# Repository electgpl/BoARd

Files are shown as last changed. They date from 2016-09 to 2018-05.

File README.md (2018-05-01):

# Board

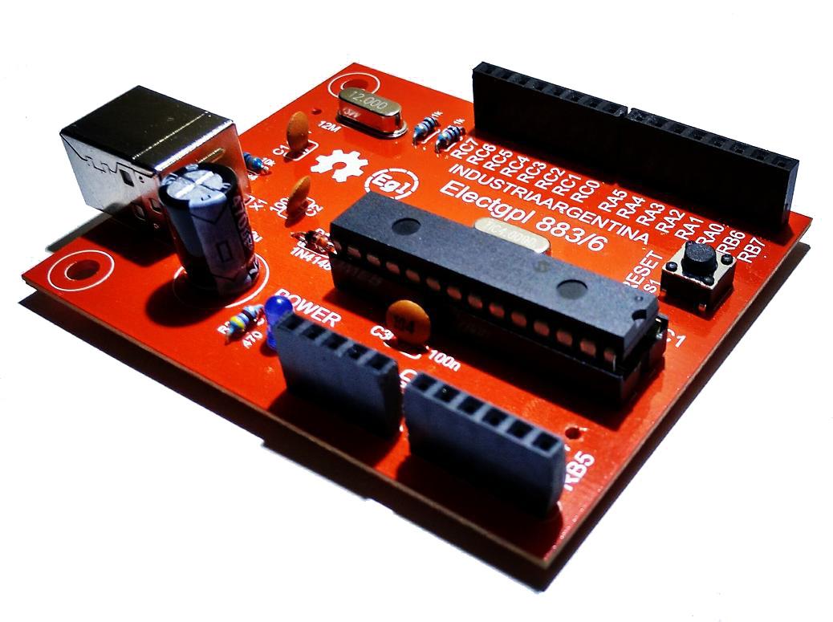
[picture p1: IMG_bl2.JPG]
N|Solid


Placa de desarrollo basada en Microchip de bajo costo, proyecto realizado de manera simple para poder ser replicado por alumnos de escuelas sin la necesidad de importar componentes y con la facilidad de realizar el circuito impreso por ellos mismos en una sola capa

  - [picc] PIC16F883 con Bootloader (Carga de fuente y Terminal Serie)
  - PCB Simple en 1 Layer realizado con Eagle
  - Bootloader oficial Micochip (AN1310) 9600bps
  - Multiples IDEs y lenguajes

Se ha probado con diversos IDEs y Lenguajes con resultados satisfactorios

> [picc] - PCWHD (PICC)
> [mplabx] - MPALB X
> [mikroc] - MikroC
> [ldmicro] - LDmicro
> [eagle] - Eagle

## Lenguajes

* Assembly
* C
* C++
* Basic
* Visual
* Ladder
* Scratch

### Instalacion (Windows)

Se debe descargar el acrhivo zip de la nota AN1310, donde encontraremos el programa ejecutable de Windows.
[AN1310]

License
----

MIT

**Free Software, Hell Yeah!**

   [picc]: <http://www.ccsinfo.com/>
   [mplabx]: <http://www.microchip.com/mplab/mplab-x-ide>
   [eagle]: <https://www.autodesk.com/education/free-software/eagle>
   [mikroc]: <https://www.mikroe.com/mikroc/>
   [ldmicro]: <http://cq.cx/ladder.pl>
   [AN1310]: <http://www.microchip.com/wwwAppNotes/AppNotes.aspx?appnote=en546974>

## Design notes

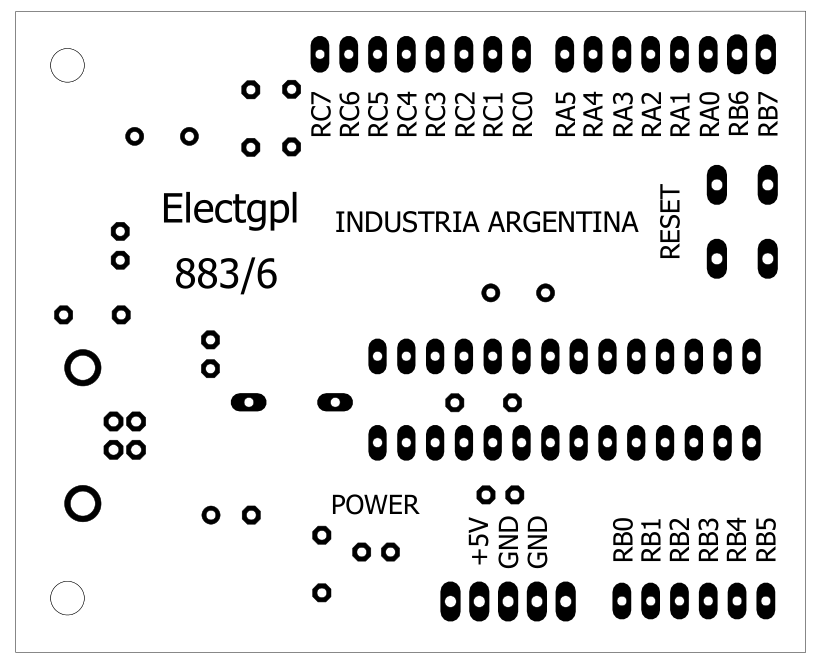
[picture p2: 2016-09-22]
Electgpl F883-6 THT Rev1 SER.PNG

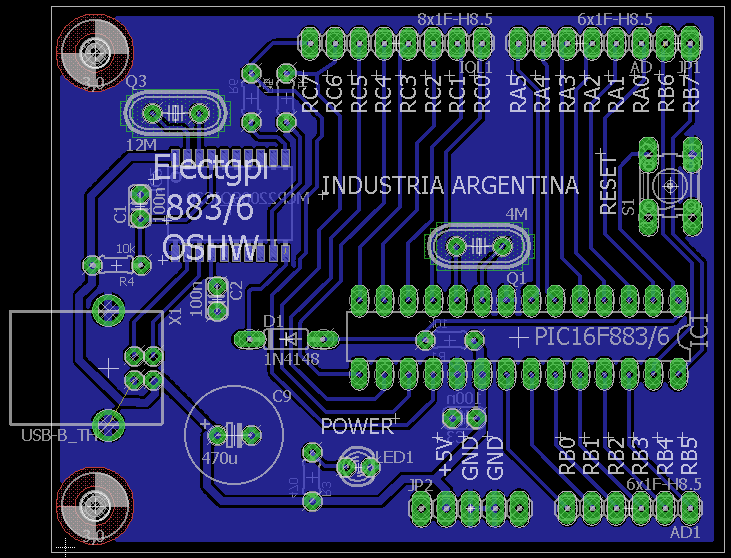
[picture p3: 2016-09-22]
Electgpl F883-6 THT Rev1 DISP.PNG

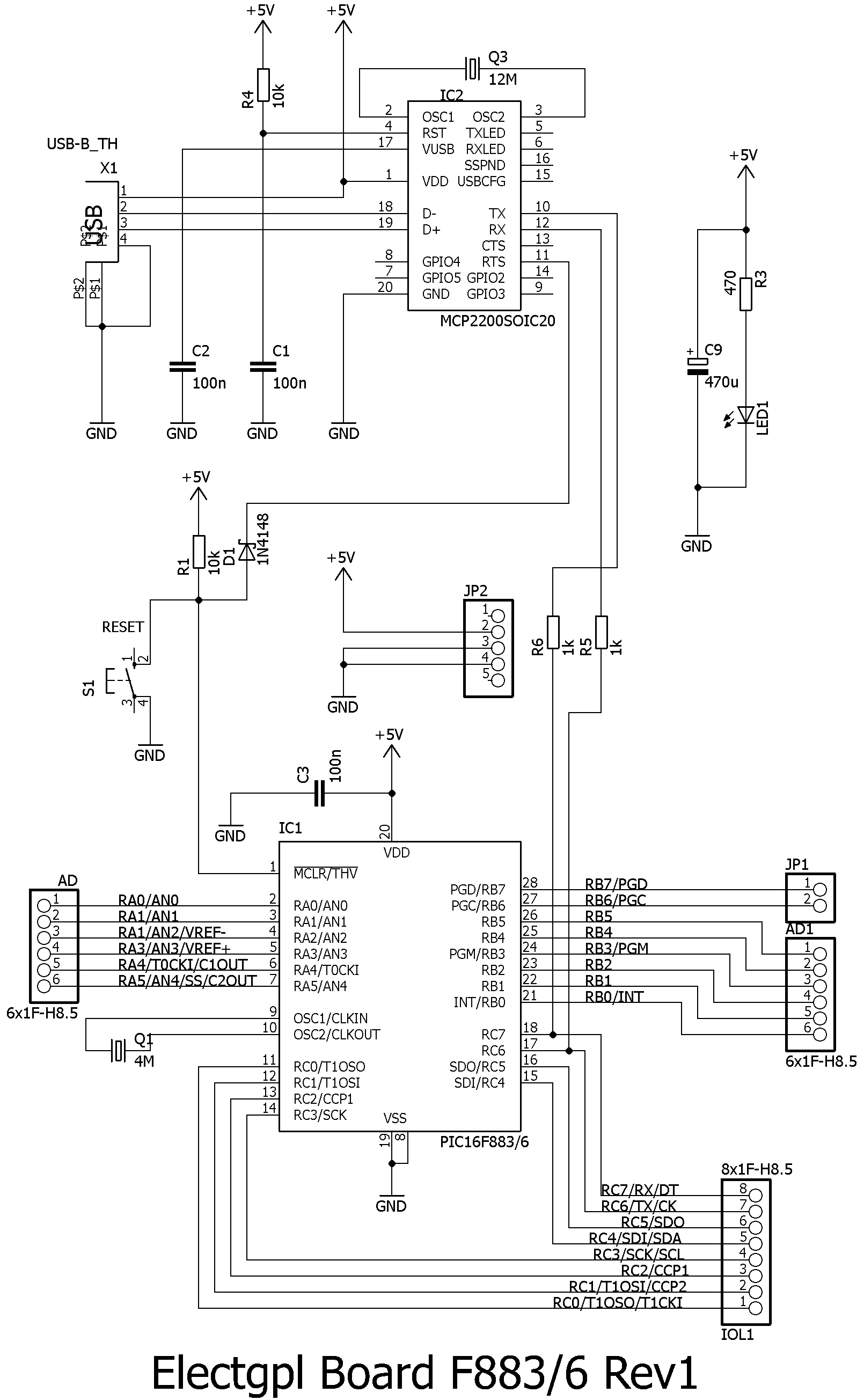
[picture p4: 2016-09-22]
Electgpl F883-6 THT Rev1 SCH.PNG

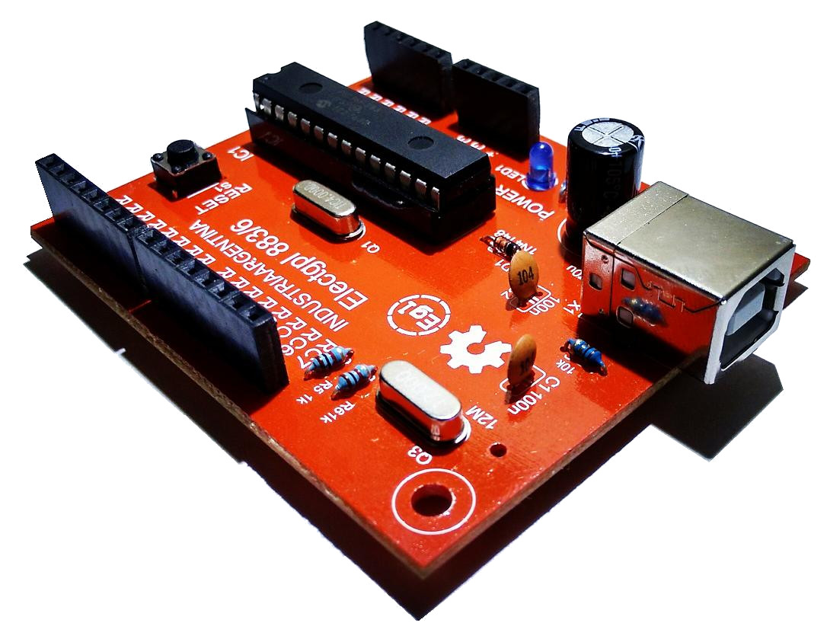
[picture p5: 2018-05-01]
IMG_bl1.JPG

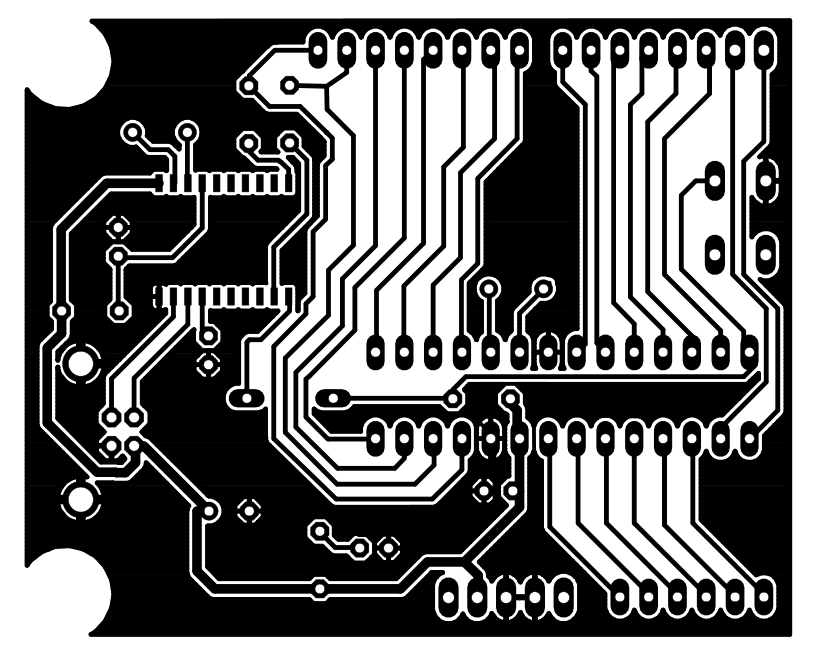
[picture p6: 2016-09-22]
Electgpl F883-6 THT Rev1 PCB.PNG

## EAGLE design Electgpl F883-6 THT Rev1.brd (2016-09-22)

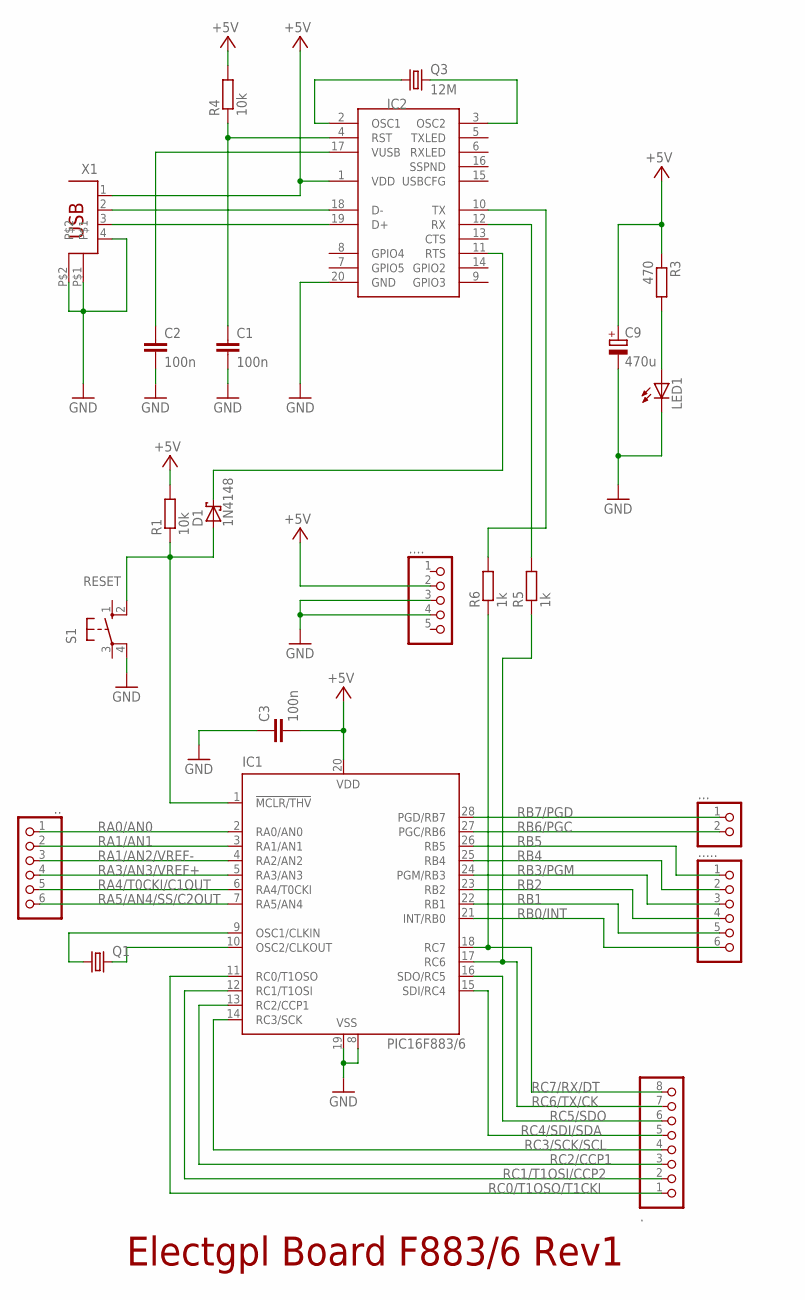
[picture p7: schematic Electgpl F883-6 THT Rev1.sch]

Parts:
.: PINHD-1X8; 1X08
.., .....: PINHD-1X6; 1X06
...: PINHD-1X2; 1X02
....: PINHD-1X5; 1X05
C1, C2, C3: 100n; C025-024X044
C9: 470u; E3,5-10
D1: 1N4148; DO35-7
IC1: PIC16F883/6; DIL28-3
IC2: MCP2200SOIC20; SOIC20
LED1: LED3MM
Q1: CRYSTALHC49S; HC49/S
Q3: 12M; HC49/S
R1, R4: 10k; 0204/5
R3: 470; 0204/5
R5, R6: 1k; 0204/5
S1: 10-XX; B3F-10XX
X1: PN61729

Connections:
+5V: .....2, C3.2, C9.+, IC1.20 (VDD), IC2.1 (VDD), R1.2, R3.1, R4.2, X1.1
GND: .....3, .....4, C1.2, C2.2, C3.1, C9.-, IC1.8 (VSS), IC1.19 (VSS), IC2.20 (GND), LED1.K (C), S1.4 (P1), X1.4, X1.P$1, X1.P$2
unnamed: IC1.10 (OSC2/CLKOUT), Q1.2
unnamed: IC1.9 (OSC1/CLKIN), Q1.1
unnamed: LED1.A, R3.2
unnamed: D1.C, IC2.11 (RTS)
unnamed: IC2.18 (D-), X1.2
unnamed: IC2.12 (RX), R5.2
unnamed: IC2.10 (TX), R6.2
unnamed: IC2.19 (D+), X1.3
unnamed: C1.1, IC2.4 (RST), R4.1
unnamed: IC2.2 (OSC1), Q3.1
unnamed: IC2.3 (OSC2), Q3.2
unnamed: C2.1, IC2.17 (VUSB)
RA0/AN0: ...1, IC1.2 (RA0/AN0)
RA1/AN1: ...2, IC1.3 (RA1/AN1)
RA1/AN2/VREF-: ...3, IC1.4 (RA2/AN2)
RA3/AN3/VREF+: ...4, IC1.5 (RA3/AN3)
RA4/T0CKI/C1OUT: ...5, IC1.6 (RA4/T0CKI)
RA5/AN4/SS/C2OUT: ...6, IC1.7 (RA5/AN4)
RB0/INT: ......6, IC1.21 (INT/RB0)
RB1: ......5, IC1.22 (RB1)
RB2: ......4, IC1.23 (RB2)
RB3/PGM: ......3, IC1.24 (PGM/RB3)
RB4: ......2, IC1.25 (RB4)
RB5: ......1, IC1.26 (RB5)
RB6/PGC: ....2, IC1.27 (PGC/RB6)
RB7/PGD: ....1, IC1.28 (PGD/RB7)
RC0/T1OSO/T1CKI: ..1, IC1.11 (RC0/T1OSO)
RC1/T1OSI/CCP2: ..2, IC1.12 (RC1/T1OSI)
RC2/CCP1: ..3, IC1.13 (RC2/CCP1)
RC3/SCK/SCL: ..4, IC1.14 (RC3/SCK)
RC4/SDI/SDA: ..5, IC1.15 (SDI/RC4)
RC5/SDO: ..6, IC1.16 (SDO/RC5)
RC6/TX/CK: ..7, IC1.17 (RC6), R5.1
RC7/RX/DT: ..8, IC1.18 (RC7), R6.1
RESET: D1.A, IC1.1 (!MCLR/THV), R1.1, S1.2 (S1)

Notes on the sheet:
Electgpl Board F883/6 Rev1

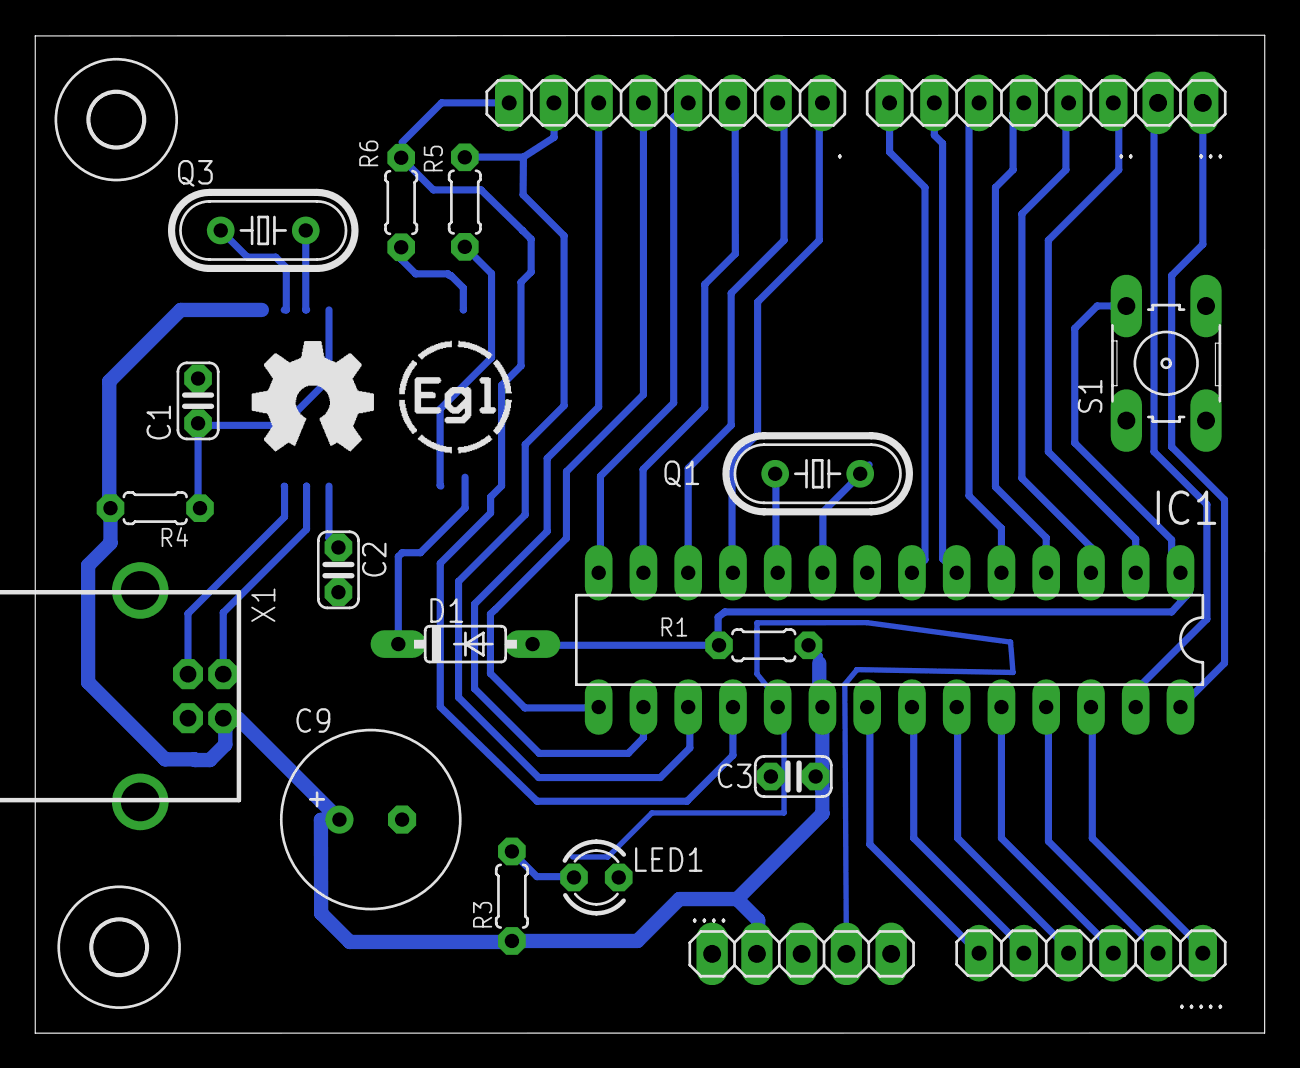
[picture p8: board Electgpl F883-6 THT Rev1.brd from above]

Board: 2 copper layers, 69.8 x 56.6 mm, 24 parts (1 on the bottom side), 37 nets.

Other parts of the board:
U$2, U$3: 3,0

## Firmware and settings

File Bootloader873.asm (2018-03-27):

; Copyright (c) 2002-2009,  Microchip Technology Inc.
;
; Microchip licenses this software to you solely for use with Microchip
; products.  The software is owned by Microchip and its licensors, and
; is protected under applicable copyright laws.  All rights reserved.
;
; SOFTWARE IS PROVIDED "AS IS."  MICROCHIP EXPRESSLY DISCLAIMS ANY
; WARRANTY OF ANY KIND, WHETHER EXPRESS OR IMPLIED, INCLUDING BUT
; NOT LIMITED TO, THE IMPLIED WARRANTIES OF MERCHANTABILITY, FITNESS
; FOR A PARTICULAR PURPOSE, OR NON-INFRINGEMENT.  IN NO EVENT SHALL
; MICROCHIP BE LIABLE FOR ANY INCIDENTAL, SPECIAL, INDIRECT OR
; CONSEQUENTIAL DAMAGES, LOST PROFITS OR LOST DATA, HARM TO YOUR
; EQUIPMENT, COST OF PROCUREMENT OF SUBSTITUTE GOODS, TECHNOLOGY
; OR SERVICES, ANY CLAIMS BY THIRD PARTIES (INCLUDING BUT NOT LIMITED
; TO ANY DEFENSE THEREOF), ANY CLAIMS FOR INDEMNITY OR CONTRIBUTION,
; OR OTHER SIMILAR COSTS.
;
; To the fullest extent allowed by law, Microchip and its licensors
; liability shall not exceed the amount of fees, if any, that you
; have paid directly to Microchip to use this software.
;
; MICROCHIP PROVIDES THIS SOFTWARE CONDITIONALLY UPON YOUR ACCEPTANCE
; OF THESE TERMS.
;
; Author        Date        Comment
; ************************************************************************
; E. Schlunder  07/17/2009  Bringing back support for bootloader at 
;                           address 0 for hardware boot block write
;                           protect.
; E. Schlunder  05/08/2009  Upgrade to support new Serial Bootloader 
;                           features and protocol.
;
; Bootloader for PIC16F by Rodger Richey
; Adapted from PIC18F bootloader developed by Ross Fosler
; 03/18/2002    ... First full implementation
; 03/25/2002    Modified receive & parse engine to vector to autobaud on a checksum 
;               error since a checksum error could likely be a communications problem.
;               Modified the protocol to incorporate the autobaud as part of the 
;               first received <STX>. Doing this improves robustness by allowing
;               re-sync under any condition. Previously it was possible to enter a 
;               state where only a hard reset would allow re-syncing.
; 04/09/2002    Fixed bugs: 1) clear carry before shifting ABTIME in Autobaud
;                           2) Increment address in program memory write
;                           3) Increment address in program memory read
; 06/07/2002    Fixed bug in read, byte counter in code is word counter.  Needed
;               to multiply by 2 to get bytes.
;
; *****************************************************************************

; *****************************************************************************
#include "devices.inc"
#include "bankswitch.inc"
#include "bootconfig.inc"
; *****************************************************************************

; *****************************************************************************

#if BOOTLOADERSIZE < ERASE_FLASH_BLOCKSIZE
    ; This device has a large Erase FLASH Block Size, so we need to reserve a full Erase Block
    ; page for the bootloader. Reserving an entire erase block prevents the PC application
    ; from accidently erasing a portion of the bootloader.
    #define BOOTBLOCKSIZE ERASE_FLASH_BLOCKSIZE
    #ifndef BOOTLOADER_ADDRESS
        #ifdef CONFIG_AS_FLASH
            #define BOOTLOADER_ADDRESS  (END_FLASH - BOOTBLOCKSIZE - ERASE_FLASH_BLOCKSIZE)
        #else
            #define BOOTLOADER_ADDRESS  (END_FLASH - BOOTBLOCKSIZE)
        #endif
    #endif
#else
    #if (BOOTLOADERSIZE % ERASE_FLASH_BLOCKSIZE) == 0
        #define BOOTBLOCKSIZE BOOTLOADERSIZE     
    #else
        #define BOOTBLOCKSIZE (BOOTLOADERSIZE / ERASE_FLASH_BLOCKSIZE + 1) * ERASE_FLASH_BLOCKSIZE
    #endif
    #ifndef BOOTLOADER_ADDRESS
        #define BOOTLOADER_ADDRESS  (END_FLASH - BOOTBLOCKSIZE)
    #endif
#endif

#ifndef AppVector 
    ; The application startup GOTO instructions will be written just before the Boot Block,
    ; courtesy of the host PC bootloader application.
    #define AppVector (BootloaderStart-.5)
#endif

; *****************************************************************************
#define STX             0x0F
#define ETX             0x04
#define DLE             0x05
#define NTX             0xFF
; *****************************************************************************

; *****************************************************************************
CRCL                equ 0xA0        ; GPR RAM in bank 1
CRCH                equ 0xA1
RXDATA              equ 0xA2
TXDATA              equ 0xA3

; Framed Packet Format
; <STX>[<COMMAND><ADDRL><ADDRH><ADDRU><0x00><DATALEN><...DATA...>]<CRCL><CRCH><ETX>

COMMAND             equ 0x20        ; receive buffer in bank 0
ADDRESS_L           equ 0x21
ADDRESS_H           equ 0x22
ADDRESS_U           equ 0x23
ADDRESS_X           equ 0x24
DATA_COUNTL         equ 0x25
PACKET_DATA         equ 0x26
DATA_COUNTH         equ 0x26        ; only for certain commands

#if BOOTLOADER_ADDRESS == 0
#ifndef BSR
PCLATH_TEMP	        equ	0x7E		; Interrupt context save/restore temporary memory
W_TEMP		        equ	0x7F
#endif
#endif
; *****************************************************************************

#ifdef PORTC
    ; Most parts have the UART on RC7 and RC6 pins.
    #define PORTRX  PORTC
    #define RXPIN   7

    #define TRISTX  TRISC
    #define TXPIN   6
#else
    ; PIC16F88 doesn't have PORTC, so the UART pins are elsewhere...
    #define PORTRX  PORTB
    #define RXPIN   2

    #define TRISTX  TRISB
    #define TXPIN   5
#endif
 
    errorlevel -302                 ; Do not show any banking warnings
; *****************************************************************************
#if BOOTLOADER_ADDRESS != 0
    ORG     0
    ; The following GOTO is not strictly necessary, but may startup faster
    ; if running at slow clock speeds.
        errorlevel -306             ; Do not show any page boundary warnings
;    nop                                 
;    movlw   high(BootloaderBreakCheck)
;    movwf   PCLATH                  ; Bx
;    goto    BootloaderBreakCheck
        errorlevel +306             ; Do not show any page boundary warnings

    ORG     BOOTLOADER_ADDRESS
BootloaderStart:
    movlw   high(BootloadMode)
    movwf   PCLATH                  ; Bx
    goto    BootloadMode
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
